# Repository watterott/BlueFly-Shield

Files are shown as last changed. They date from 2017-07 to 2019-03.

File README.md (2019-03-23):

# BlueFly-Shield
The BlueFly-Shield is a plug-on module with WiFi/WLAN for Arduino based on a Microchip WINC1500 WiFi Network Controller SoC.

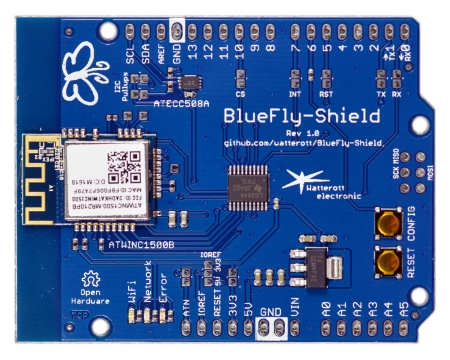
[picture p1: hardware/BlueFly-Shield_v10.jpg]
BlueFly-Shield


* Compatible with [Arduino WiFi-Shield-101](https://www.arduino.cc/en/Main/ArduinoWiFiShield101)
* [Microchip ATWINC1500B](http://www.microchip.com/wwwproducts/en/ATWINC1500) WiFi Network Controller (SPI)
* [Microchip ATECC508A](http://www.microchip.com/wwwproducts/en/ATECC508A) Crypto Authentication (I2C address 0x60)
* Integrated WiFi and IPv4 stack
* 3.3V - 5V tolerant IOs
* Open-Source and released under the [Creative Commons Attribution Share-Alike License](https://creativecommons.org/licenses/by-sa/4.0/).
* **[Documentation on learn.watterott.com](https://learn.watterott.com)**

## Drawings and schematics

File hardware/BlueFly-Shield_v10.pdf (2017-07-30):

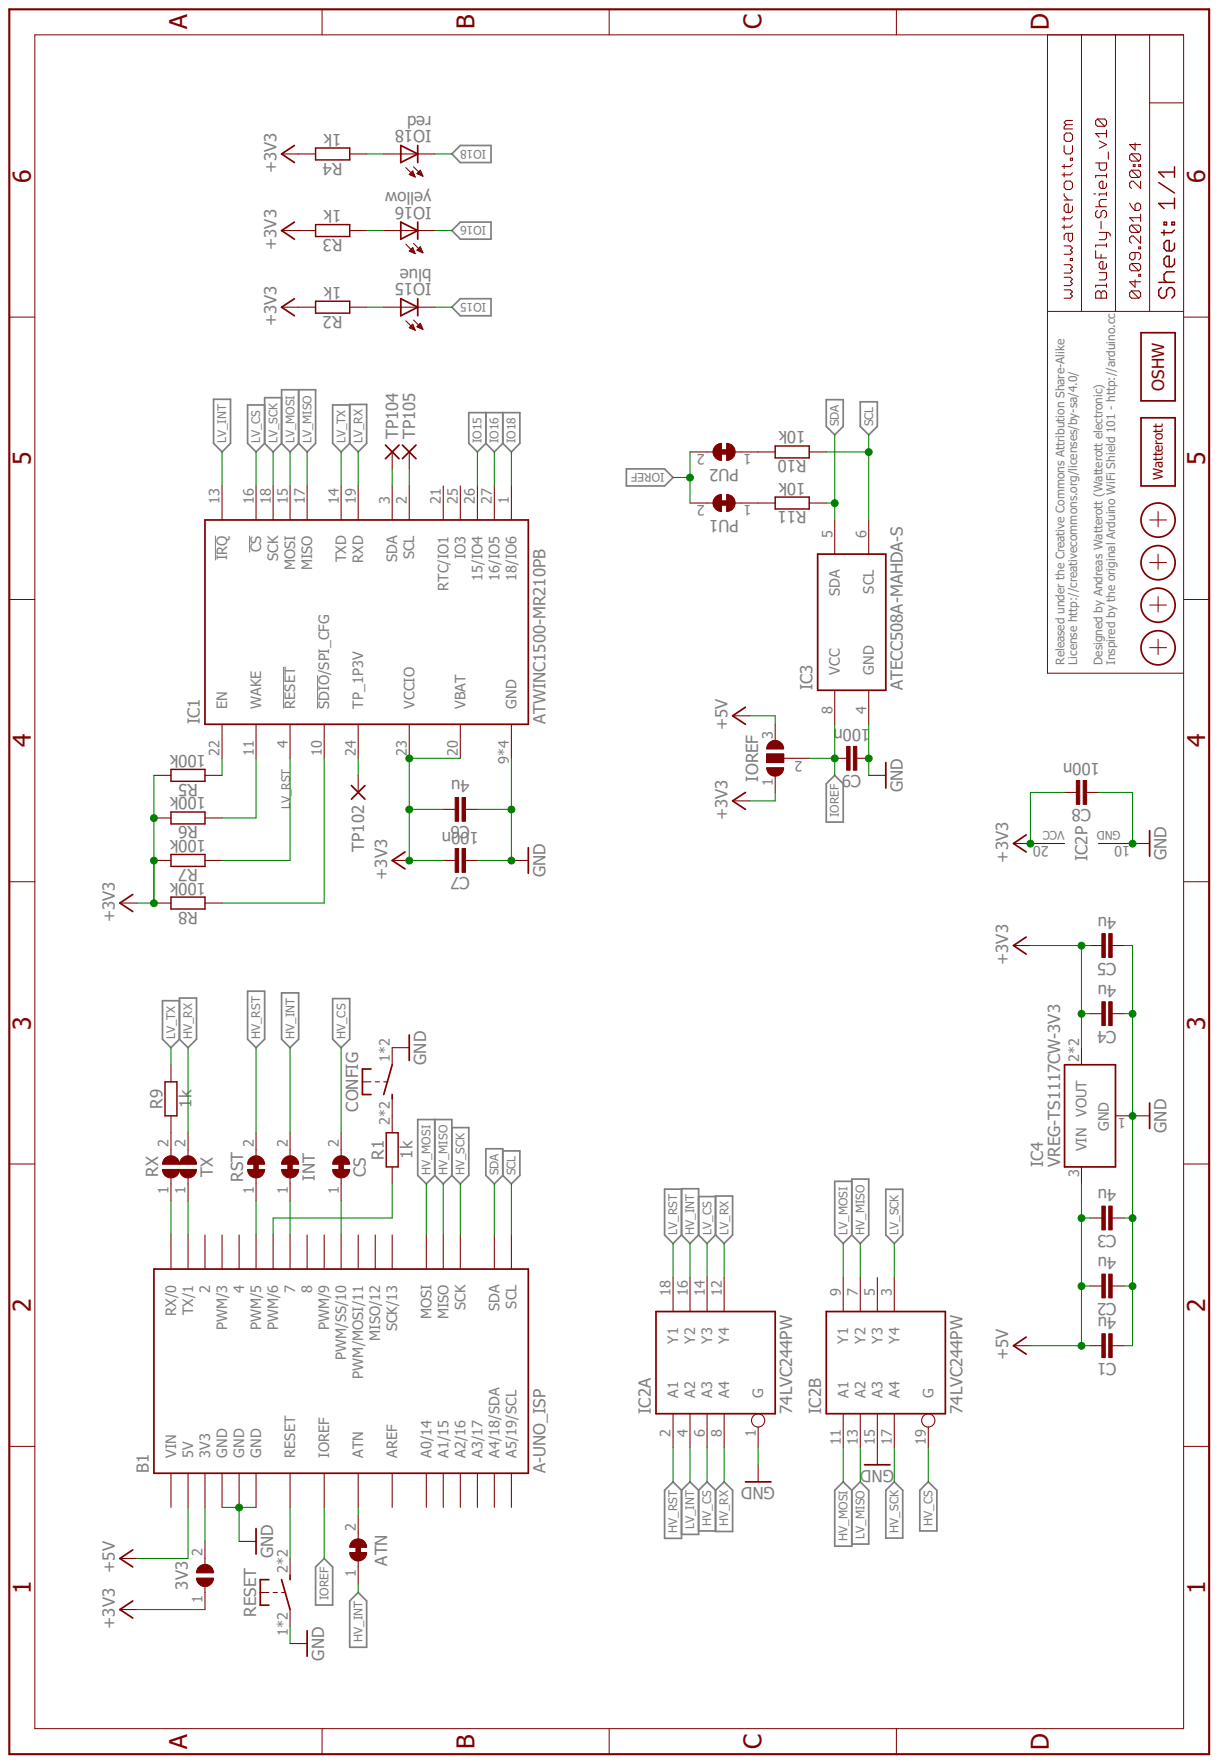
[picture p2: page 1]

Inspired by the original Arduino WiFi Shield 101 - http://arduino.cc

Released under the Creative Commons Attribution Share-Alike

License http://creativecommons.org/licenses/by-sa/4.0/

Designed by Andreas Watterott (Watterott electronic)

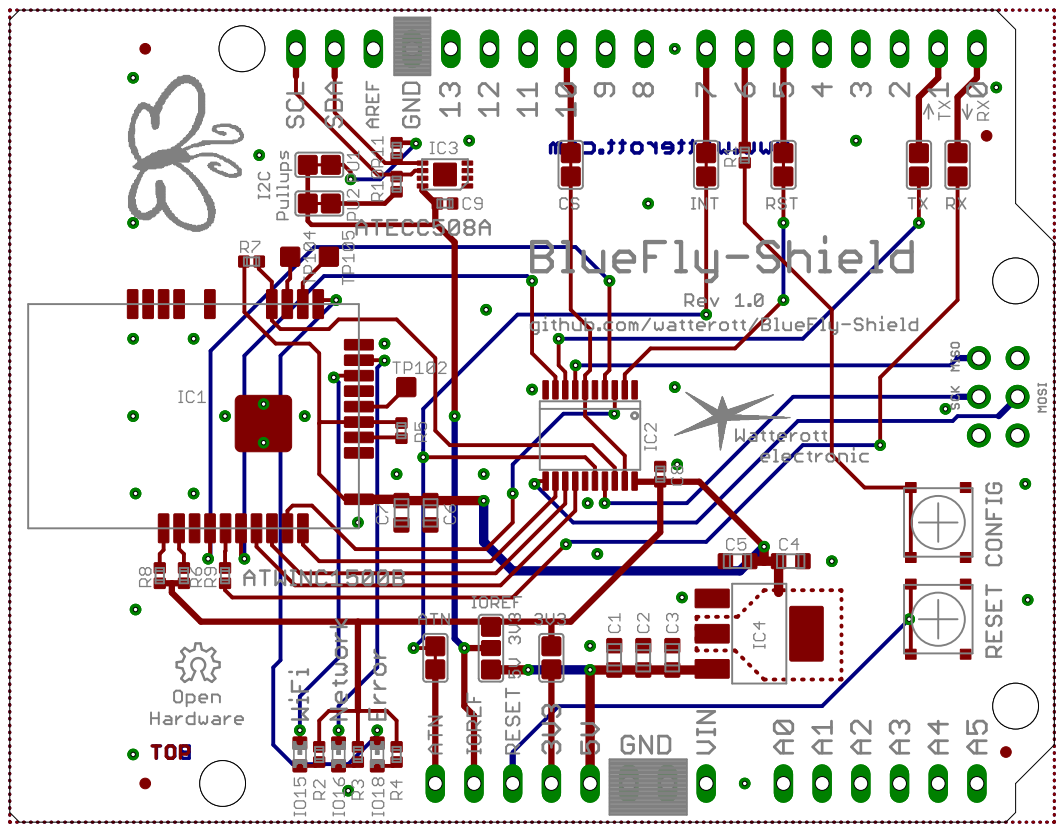
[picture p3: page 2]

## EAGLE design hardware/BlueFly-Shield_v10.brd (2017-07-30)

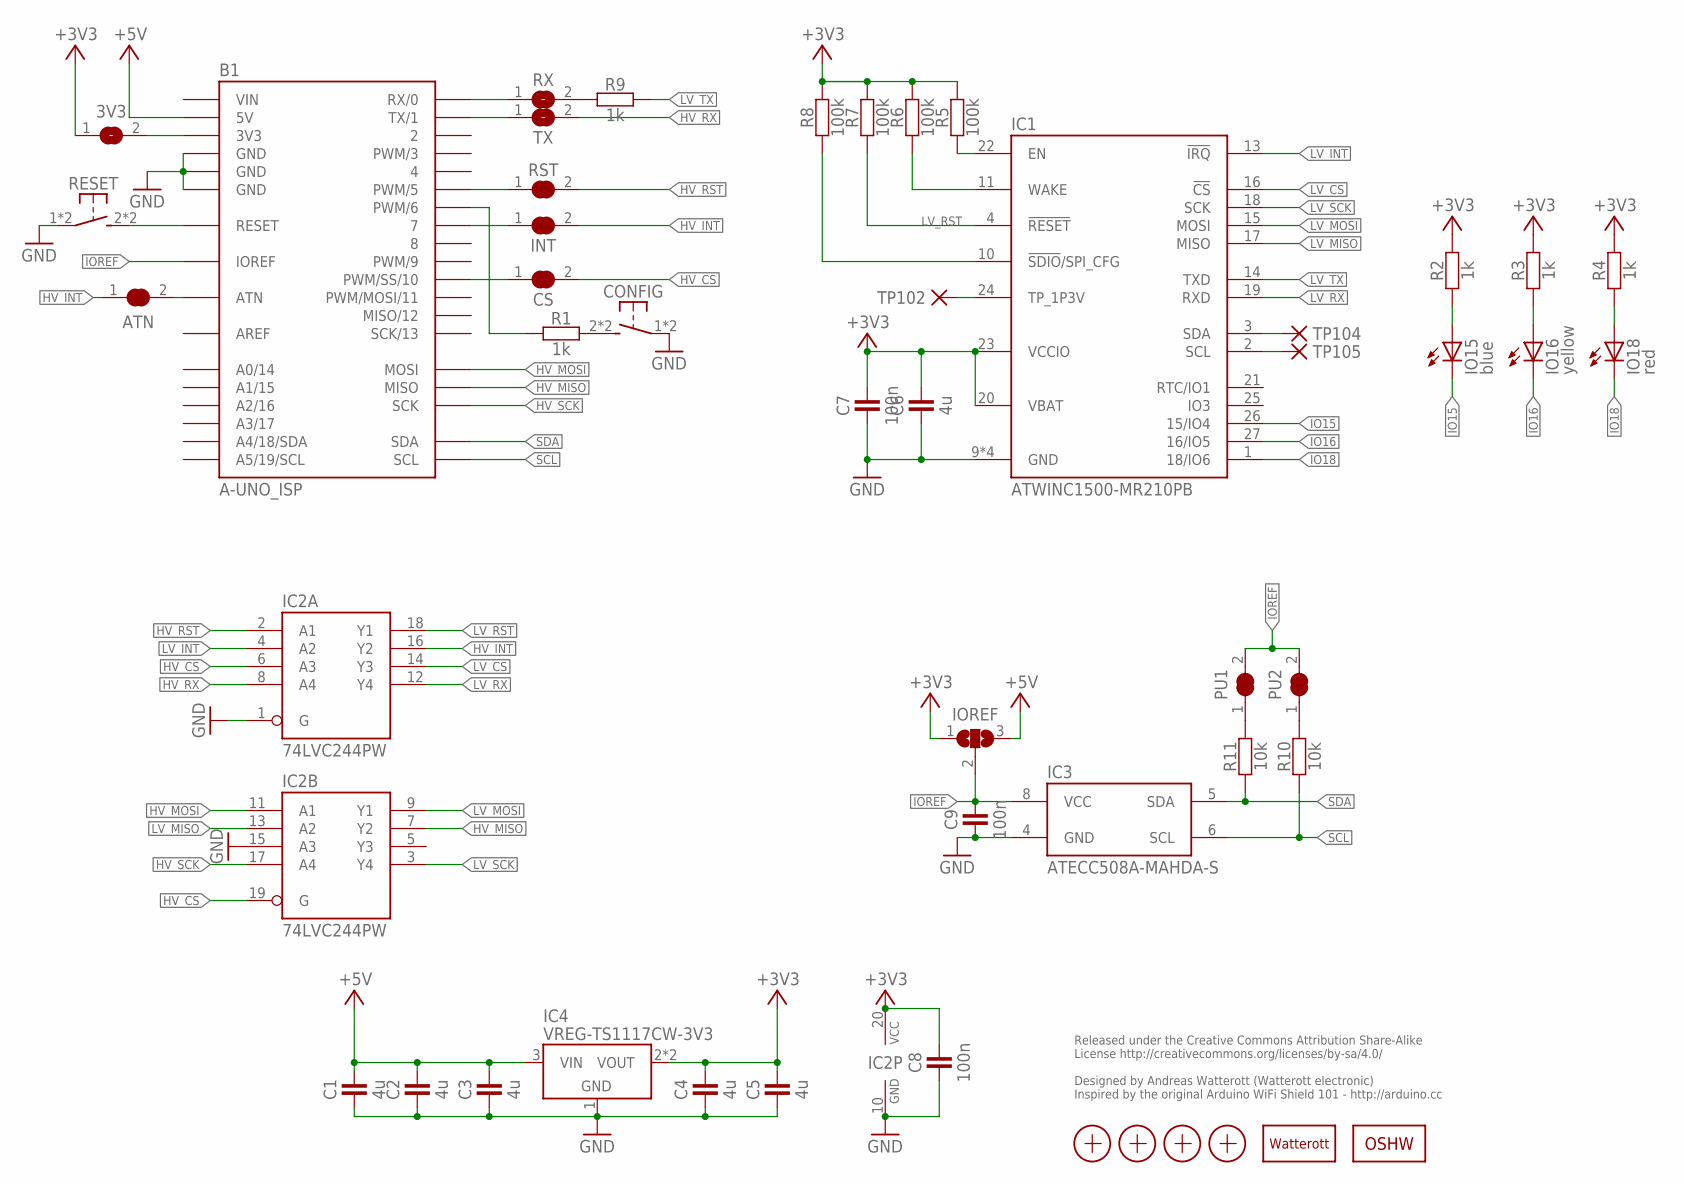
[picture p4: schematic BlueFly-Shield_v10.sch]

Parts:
3V3: JUMPER2-0603-NC; JUMPER2-0603_NC
ATN: JUMPER2-0603-NC; JUMPER2-0603_NC
B1: A-UNO_ISP; A-UNO-ISP
C1, C2, C3, C4, C5, C6: 4u; C0603
C7: 100n; C0603
C8, C9: 100n; C0402
CONFIG: SW-TACTILE-TL3315; TL3315N
CS: JUMPER2-0603-NC; JUMPER2-0603_NC
IC1: ATWINC1500-MR210PB; ATWINC1500-MX210
IC2: 74LVC244PW; TSSOP20
IC3: ATECC508A-MAHDA-S; UDFN8
IC4: VREG-TS1117CW-3V3; SOT223
INT: JUMPER2-0603-NC; JUMPER2-0603_NC
IO15: blue; C0603
IO16: yellow; C0603
IO18: red; C0603
IOREF: JUMPER3-0603-NC; JUMPER3-0603_NC
LOGO1: LOGO-S_PLACE_M; SPARK_TPLACE_M
LOGO2: OSHW_LOGOX0100; OSHW_6X100
PU1, PU2: JUMPER2-0603-NC; JUMPER2-0603_NC
R1, R2, R3, R4, R9: 1k; C0402
R5, R6, R7, R8: 100k; C0402
R10, R11: 10k; C0402
RESET: SW-TACTILE-TL3315; TL3315N
RST: JUMPER2-0603-NC; JUMPER2-0603_NC
RX: JUMPER2-0603-NC; JUMPER2-0603_NC
TP102, TP104, TP105: PAD-1.27X1.27_NC
TX: JUMPER2-0603-NC; JUMPER2-0603_NC
X1, X2, X3, X4: PASSER-07; PASSER_07MM

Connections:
3V3: 3V3.2, B1.3V3
+3V3: 3V3.1, C4.2, C5.2, C6.2, C7.2, C8.2, IC1.20 (VBAT), IC1.23 (VCCIO), IC2.20 (VCC), IC4.2 (VOUT), IC4.4 (VOUT), IOREF.1, R2.2, R3.2, R4.2, R5.2, R6.2, R7.2, R8.2
+5V: B1.5V, C1.2, C2.2, C3.2, IC4.3 (VIN), IOREF.3
AREF: B1.AREF
ATN: ATN.2, B1.ATN
BTN: CONFIG.2 (S1), CONFIG.3 (S1), R1.2
D0: B1.0 (RX/0), RX.1
D1: B1.1 (TX/1), TX.1
D5: B1.5 (PWM/5), RST.1
D7: B1.7, INT.1
D10: B1.10 (PWM/SS/10), CS.1
DF6: B1.6 (PWM/6), R1.1
GND: B1.GND@1 (GND), B1.GND@2 (GND), B1.GND@3 (GND), C1.1, C2.1, C3.1, C4.1, C5.1, C6.1, C7.1, C8.1, C9.1, CONFIG.1, CONFIG.4 (P1), IC1.9 (GND), IC1.12 (GND), IC1.28 (GND), IC1.GND, IC2.1 (G), IC2.10 (GND), IC2.15 (A3), IC3.4 (GND), IC4.1 (GND), RESET.1, RESET.4 (P1)
HV_CS: CS.2, IC2.6 (A3), IC2.19 (G)
HV_INT: ATN.1, IC2.16 (Y2), INT.2
HV_MISO: B1.MISO, IC2.7 (Y2)
HV_MOSI: B1.MOSI, IC2.11 (A1)
HV_RST: IC2.2 (A1), RST.2
HV_RX: IC2.8 (A4), TX.2
HV_SCK: B1.SCK, IC2.17 (A4)
IO15: IC1.26 (15/IO4), IO15.C
IO16: IC1.27 (16/IO5), IO16.C
IO18: IC1.1 (18/IO6), IO18.C
IOREF: B1.IOREF, C9.2, IC3.8 (VCC), IOREF.2, PU1.2, PU2.2
LED15: IO15.A, R2.1
LED16: IO16.A, R3.1
LED18: IO18.A, R4.1
LV_CS: IC1.16 (!CS), IC2.14 (Y3)
LV_EN: IC1.22 (EN), R5.1
LV_INT: IC1.13 (!IRQ), IC2.4 (A2)
LV_MISO: IC1.17 (MISO), IC2.13 (A2)
LV_MOSI: IC1.15 (MOSI), IC2.9 (Y1)
LV_RST: IC1.4 (!RESET), IC2.18 (Y1), R7.1
LV_RX: IC1.19 (RXD), IC2.12 (Y4)
LV_SCK: IC1.18 (SCK), IC2.3 (Y4)
LV_TX: IC1.14 (TXD), R9.2
LV_WAKE: IC1.11 (WAKE), R6.1
unnamed: R9.1, RX.2
unnamed: PU2.1, R10.2
unnamed: PU1.1, R11.2
RST: B1.RST@1 (RESET), RESET.2 (S1), RESET.3 (S1)
SCL: B1.SCL, IC3.6 (SCL), R10.1
SDA: B1.SDA, IC3.5 (SDA), R11.1
SPI_CFG: IC1.10 (!SDIO!/SPI_CFG), R8.1
TP: IC1.24 (TP_1P3V), TP102.1
VIN: B1.VIN
WIFI_SCL: IC1.2 (SCL), TP105.1
WIFI_SDA: IC1.3 (SDA), TP104.1

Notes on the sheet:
Released under the Creative Commons Attribution Share-Alike License http://creativecommons.org/licenses/by-sa/4.0/ Designed by Andreas Watterott (Watterott electronic) Inspired by the original Arduino WiFi Shield 101 - http://arduino.cc

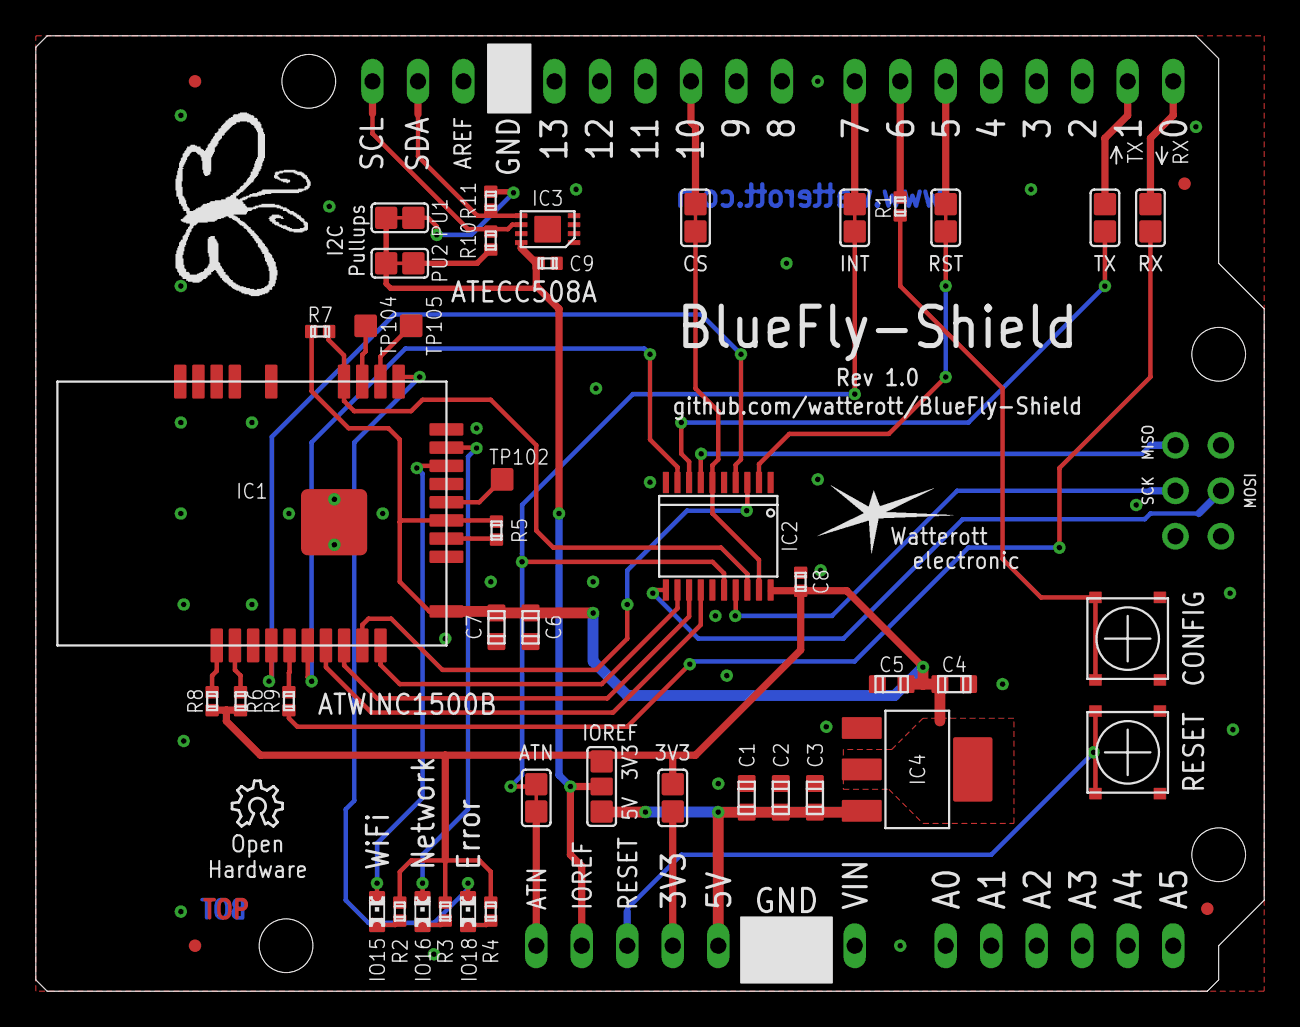
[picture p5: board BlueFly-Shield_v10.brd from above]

Board: 2 copper layers, 68.6 x 53.3 mm, 49 parts (0 on the bottom side), 46 nets.
